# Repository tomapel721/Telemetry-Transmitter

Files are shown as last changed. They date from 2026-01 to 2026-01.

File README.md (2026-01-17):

## :book: Long story short
The transmitter part of telemetry system which was implemented inside a Formula Student EV.

## :computer: How it works - technologies
PCB Design: **KiCad**

Project source code: **C (C18) with usage of HAL libraries**
Board used: **STM32L432KC**

## :file_folder: Repository structure
In main directory, you can find 2 folders:
- directory **PCBDesign** contains project of printed circuit used as HW part of the telemetry transmitter
- directory **SourceCode** contains the SW part of the project
obraz

## :scroll: How to use my code
Usage of the code can be hard to do, but in case you want to make your own racing car, here is the brief manual:
1. Print the PCB using the _GERBER_ files
2. Solder the board elements
3. Connect soldered electronics to PC
4. Flash the STM32 using ST-LINK debugger (pins where to connect are marked on the PCB schema)
5. Enjoy;)

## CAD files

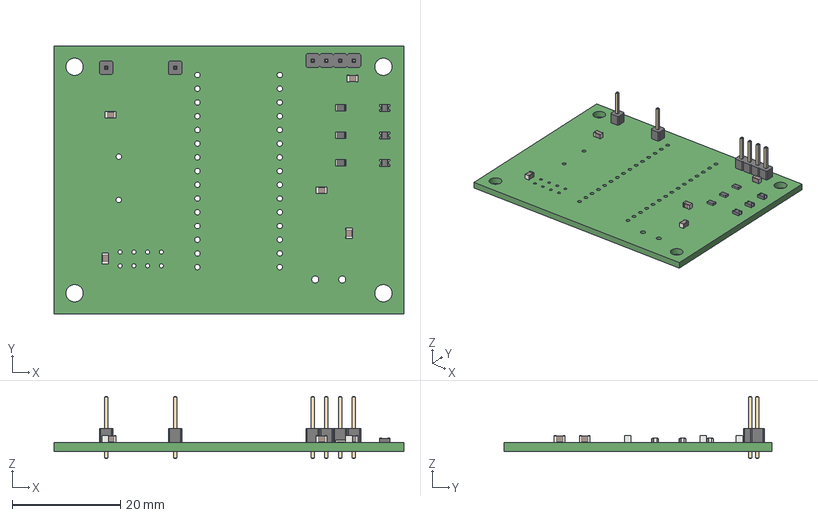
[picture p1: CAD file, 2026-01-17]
Transmitter/PCBDesign/Telemetry.step
64.8 x 49.5 x 11.5 mm

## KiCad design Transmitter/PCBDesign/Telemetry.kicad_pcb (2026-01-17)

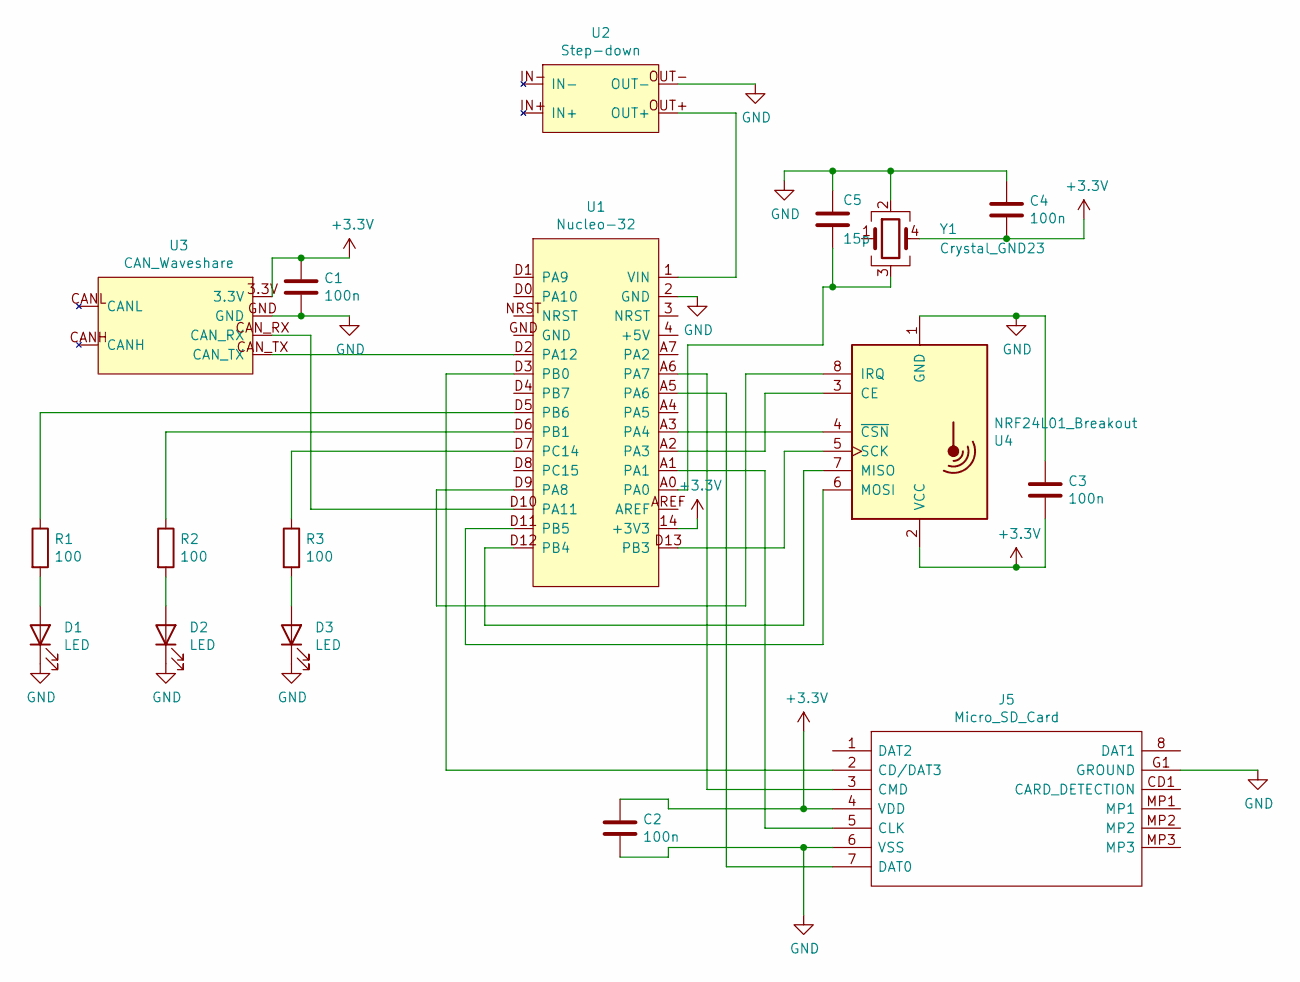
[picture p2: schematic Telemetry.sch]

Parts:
C1, C2, C3, C4: 100n; C_0805_2012Metric
C5: 15p; C_0805_2012Metric
D1, D2, D3: LED; D_0805_2012Metric_Pad1.15x1.40mm_HandSolder
J5: Micro_SD_Card; 112JTDARR01; Manufacturer_Part_Number 112J-TDAR-R01
R1, R2, R3: 100; R_0805_2012Metric_Pad1.20x1.40mm_HandSolder
U1: Nucleo-32; Arduino_Nano
U2: Step-down; TerminalBlock_RND_205-00012_1x02_P5.00mm_Horizontal
U3: CAN_Waveshare; PinHeader_1x04_P2.54mm_Vertical
U4: NRF24L01_Breakout; nRF24L01_Breakout
Y1: Crystal_GND23; Crystal_SMD_7050-4Pin_7.0x5.0mm

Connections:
+3V3: C1.1, C2.1, C3.2, C4.2, J5.4 (VDD), U1.14 (+3V3), U3.3.3V, U4.2 (VCC), Y1.4
GND: C1.2, C2.2, C3.1, C4.1, C5.1, D1.1 (K), D2.1 (K), D3.1 (K), J5.6 (VSS), J5.G1 (GROUND), U1.2 (GND), U2.OUT-, U3.GND, U4.1 (GND), Y1.2
unnamed: C5.2, U1.A0, Y1.3
unnamed: D1.2 (A), R1.2
unnamed: D2.2 (A), R2.2
unnamed: D3.2 (A), R3.2
unnamed: J5.2 (CD/DAT3), U1.D3 (PB0)
unnamed: J5.3 (CMD), U1.A6 (PA7)
unnamed: J5.5 (CLK), U1.A1
unnamed: J5.7 (DAT0), U1.A5 (PA6)
unnamed: R1.1, U1.D5 (PB6)
unnamed: R2.1, U1.D6 (PB1)
unnamed: R3.1, U1.D7 (PC14)
unnamed: U1.1 (VIN), U2.OUT+
unnamed: U1.A2 (PA3), U4.3 (CE)
unnamed: U1.A3 (PA4), U4.4 (~CSN)
unnamed: U1.D2 (PA12), U3.CAN_TX
unnamed: U1.D9 (PA8), U4.8 (IRQ)
unnamed: U1.D10 (PA11), U3.CAN_RX
unnamed: U1.D11 (PB5), U4.6 (MOSI)
unnamed: U1.D12 (PB4), U4.7 (MISO)
unnamed: U1.D13 (PB3), U4.5 (SCK)

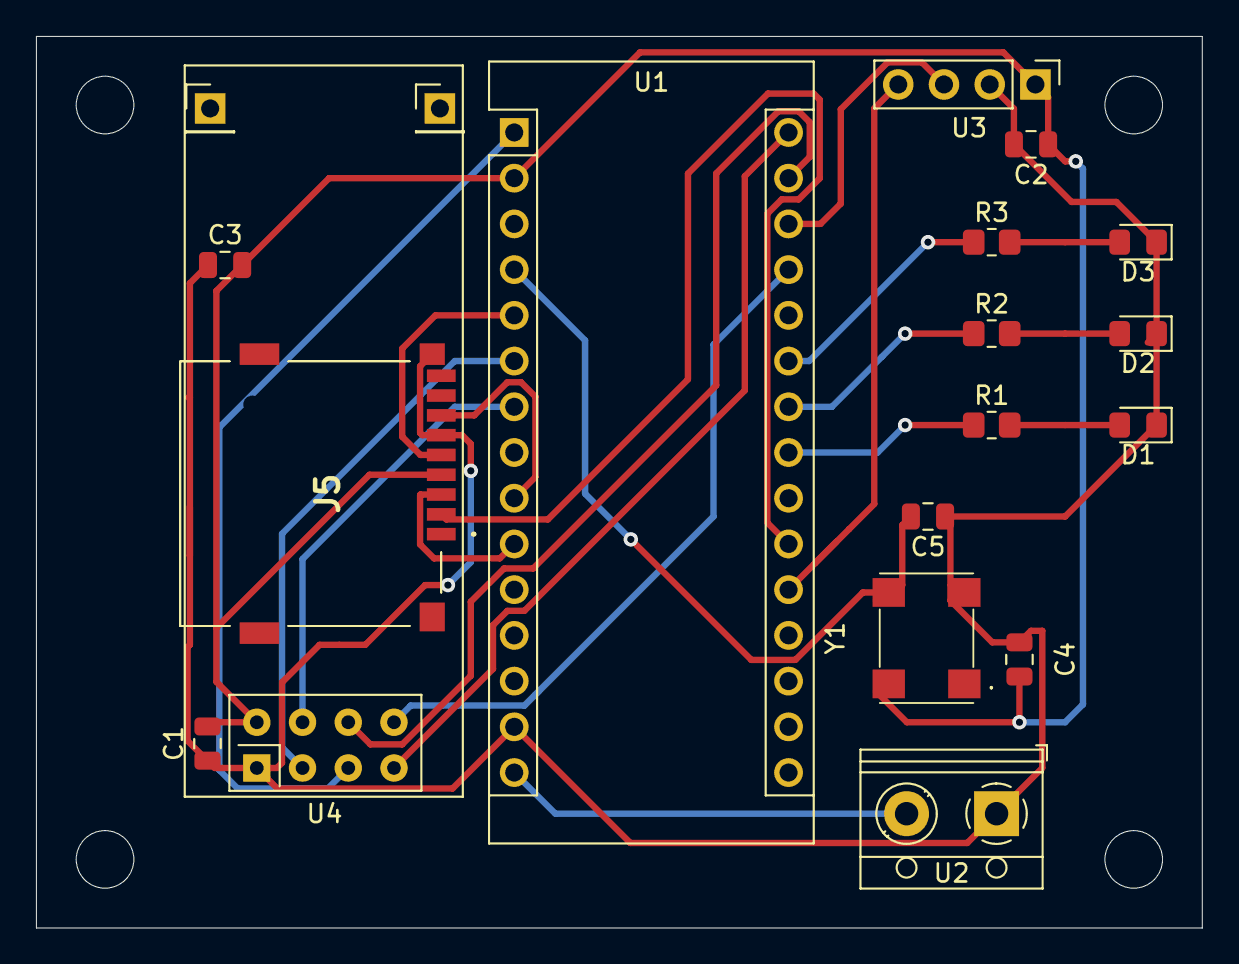
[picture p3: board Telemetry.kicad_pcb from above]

Board: 2 copper layers, 64.8 x 49.5 mm, 23 parts (0 on the bottom side), 22 nets.

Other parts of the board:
 : .; PinHeader_1x01_P2.54mm_Vertical
 #2: .; PinHeader_1x01_P2.54mm_Vertical
 #3,  #4,  #5,  #6: M3; MountingHole_3.2mm_M3_DIN965

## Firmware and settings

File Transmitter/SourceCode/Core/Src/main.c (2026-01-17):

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
/* Includes ------------------------------------------------------------------*/
#include "main.h"
#include "can.h"
#include "fatfs.h"
#include "rtc.h"
#include "spi.h"
#include "usart.h"
#include "gpio.h"

/* USER CODE BEGIN Includes */

#include "stdio.h"
#include "fatfs_sd.h"
#include "string.h"
#include <stdbool.h>
#include <NRF24/nRF24.h>
#include <NRF24/nRF24_Defs.h>
#include <Buffer/frame.h>
#include <SD/SD_helpers.h>
/* USER CODE END Includes */

/* USER CODE BEGIN PD */
#define CAN_DATA_LENGTH 8
#define FILENAME_BUFFER_LENGTH 35
#define SD_CARD_MOUNT_IMMEDIATELY 1
#define TIME_SECONDS_IN_HOUR 3600
#define TIME_MINUTES_IN_HOUR 60
#define TIME_MILISECONDS_IN_SECOND 1000000
#define SECOND_MILLENIUM 2000
/* USER CODE END PD */


void SystemClock_Config(void);
/* USER CODE BEGIN PFP */
static void readDataToBuffer(void);
/* USER CODE END PFP */

/* USER CODE BEGIN 0 */

/* SD Card-related variables */
FATFS fs = {0};
FIL fil = {0};
FRESULT fresult = {0};
char filename[FILENAME_BUFFER_LENGTH] = {0};
UINT bw = 0;
uint8_t counterSD = 0;

/* CAN-related variables */
CAN_RxHeaderTypeDef rxHeader = {0};
uint8_t rxData[CAN_DATA_LENGTH] = {0};

/* CAN buffer */
Frame bufferingFrame = {0};

/* RTC-related variables */
RTC_TimeTypeDef currentTime = {0};
RTC_DateTypeDef currentDate = {0};
uint32_t miliseconds = 0;
uint32_t seconds = 0;

/* IRQ-related variables */
bool interruptFlag = false;

/* Radio module-related variables */
const uint8_t* rxAddress = (uint8_t*)"Nad";
const uint8_t* txAddress = (uint8_t*)"Odb";

/* USER CODE END 0 */

/**
  * @brief  The application entry point.
  * @retval int
  */
int main(void)
{
  /* MCU Configuration--------------------------------------------------------*/

  /* Reset of all peripherals, Initializes the Flash interface and the Systick. */
  HAL_Init();

  /* Configure the system clock */
  SystemClock_Config();

  /* Initialize all configured peripherals */
  MX_GPIO_Init();
  MX_SPI1_Init();
  MX_CAN1_Init();
  MX_RTC_Init();
  MX_USART2_UART_Init();
  MX_SPI3_Init();
  MX_FATFS_Init();
  /* USER CODE BEGIN 2 */

  /* CAN init */
  HAL_CAN_Start(&hcan1);
  HAL_CAN_ActivateNotification(&hcan1, CAN_IT_RX_FIFO0_MSG_PENDING);

  /* Radio module init */
  nRF24_Init(&hspi3);
  nRF24_SetRXAddress(0, rxAddress);
  nRF24_SetTXAddress(txAddress);
  nRF24_TX_Mode();

  /* SD card mount */
   fresult = f_mount(&fs, "/", SD_CARD_MOUNT_IMMEDIATELY);

  /* Handle naming of file on SD card */
   HAL_RTC_GetTime(&hrtc, &currentTime, RTC_FORMAT_BIN);
   HAL_RTC_GetDate(&hrtc, &currentDate, RTC_FORMAT_BIN);
   miliseconds = ((currentTime.SecondFraction - currentTime.SubSeconds)/((float)currentTime.SecondFraction+1) * TIME_MILISECONDS_IN_SECOND);
   sprintf(filename, "LOG_%02d%02d%d_%02d%02d_%02d_%lu.txt", currentDate.Date,
		   currentDate.Month, currentDate.Year + SECOND_MILLENIUM, currentTime.Hours,
		   currentTime.Minutes, currentTime.Seconds, miliseconds);
  /* USER CODE END 2 */

  /* Infinite loop */
  /* USER CODE BEGIN WHILE */
  while (1)
  {

	  /* Radio module interrupt checker */
	  nRF24_Event();

	  /* Handling of received packet */
	  if(interruptFlag)
	  {
		 readDataToBuffer();
	  }

    /* USER CODE END WHILE */

    /* USER CODE BEGIN 3 */
  }
  /* USER CODE END 3 */
}

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
/* USER CODE BEGIN 4 */

/* Radio module interrupt callback */
void HAL_GPIO_EXTI_Callback(uint16_t GPIO_Pin)
 {
	if(GPIO_Pin == NRF24_IRQ_Pin)
	{
		nRF24_IRQ_Handler();
	}
}

/* CAN message received callback */
void HAL_CAN_RxFifo0MsgPendingCallback(CAN_HandleTypeDef* hcan)
{
	HAL_CAN_GetRxMessage(hcan, CAN_RX_FIFO0, &rxHeader, rxData);
	interruptFlag = true;
}

/* Function reads data, pack it into buffer and save data to SD card */
static void readDataToBuffer(void)
{
	HAL_RTC_GetTime(&hrtc, &currentTime, RTC_FORMAT_BIN);
	HAL_RTC_GetDate(&hrtc, &currentDate, RTC_FORMAT_BIN);
	bufferingFrame.year = currentDate.Year;
	bufferingFrame.month = currentDate.Month;
	bufferingFrame.day = currentDate.Date;
	bufferingFrame.hours = currentTime.Hours;
	bufferingFrame.minutes = currentTime.Minutes;
	bufferingFrame.seconds = currentTime.Seconds;
	miliseconds = ((currentTime.SecondFraction - currentTime.SubSeconds)/((float)currentTime.SecondFraction+1) * TIME_MILISECONDS_IN_SECOND);
	seconds = TIME_SECONDS_IN_HOUR * currentTime.Hours + TIME_MINUTES_IN_HOUR * currentTime.Minutes + currentTime.Seconds;
	memcpy(bufferingFrame.frameData, rxData, CAN_DATA_LENGTH);

	bufferingFrame.frameDLC = rxHeader.DLC;
	bufferingFrame.frameIDE = rxHeader.IDE;
	bufferingFrame.frameRTR = rxHeader.RTR;
	bufferingFrame.frameStdID = rxHeader.StdId;

	writeFrameToSDCard(&bufferingFrame);
	nRF24_SendData((uint8_t*)&bufferingFrame, sizeof(Frame));

	interruptFlag = false;
}

/* USER CODE END 4 */
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


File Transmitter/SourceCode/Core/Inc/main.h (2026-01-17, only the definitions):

#define NRF24_CE_Pin GPIO_PIN_3
#define NRF24_CE_GPIO_Port GPIOA
#define NRF24_CSN_Pin GPIO_PIN_4
#define NRF24_CSN_GPIO_Port GPIOA
#define NRF24_IRQ_Pin GPIO_PIN_8
#define NRF24_IRQ_GPIO_Port GPIOA
#define NRF24_IRQ_EXTI_IRQn EXTI9_5_IRQn

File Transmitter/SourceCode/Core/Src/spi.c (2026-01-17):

/**
  ******************************************************************************
  * @file    spi.c
  * @brief   This file provides code for the configuration
  *          of the SPI instances.
  ******************************************************************************
  * @attention
  *
  * <h2><center>&copy; Copyright (c) 2021 STMicroelectronics.
  * All rights reserved.</center></h2>
  *
  * This software component is licensed by ST under Ultimate Liberty license
  * SLA0044, the "License"; You may not use this file except in compliance with
  * the License. You may obtain a copy of the License at:
  *                             www.st.com/SLA0044
  *
  ******************************************************************************
  */

/* Includes ------------------------------------------------------------------*/
#include "spi.h"

SPI_HandleTypeDef hspi1;
SPI_HandleTypeDef hspi3;

/* SPI1 init function */
void MX_SPI1_Init(void)
{

  hspi1.Instance = SPI1;
  hspi1.Init.Mode = SPI_MODE_MASTER;
  hspi1.Init.Direction = SPI_DIRECTION_2LINES;
  hspi1.Init.DataSize = SPI_DATASIZE_8BIT;
  hspi1.Init.CLKPolarity = SPI_POLARITY_LOW;
  hspi1.Init.CLKPhase = SPI_PHASE_1EDGE;
  hspi1.Init.NSS = SPI_NSS_SOFT;
  hspi1.Init.BaudRatePrescaler = SPI_BAUDRATEPRESCALER_32;
  hspi1.Init.FirstBit = SPI_FIRSTBIT_MSB;
  hspi1.Init.TIMode = SPI_TIMODE_DISABLE;
  hspi1.Init.CRCCalculation = SPI_CRCCALCULATION_DISABLE;
  hspi1.Init.CRCPolynomial = 7;
  hspi1.Init.CRCLength = SPI_CRC_LENGTH_DATASIZE;
  hspi1.Init.NSSPMode = SPI_NSS_PULSE_ENABLE;
  if (HAL_SPI_Init(&hspi1) != HAL_OK)
  {
    Error_Handler();
  }
}
/* SPI3 init function */
void MX_SPI3_Init(void)
{

  hspi3.Instance = SPI3;
  hspi3.Init.Mode = SPI_MODE_MASTER;
  hspi3.Init.Direction = SPI_DIRECTION_2LINES;
  hspi3.Init.DataSize = SPI_DATASIZE_8BIT;
  hspi3.Init.CLKPolarity = SPI_POLARITY_LOW;
  hspi3.Init.CLKPhase = SPI_PHASE_1EDGE;
  hspi3.Init.NSS = SPI_NSS_SOFT;
  hspi3.Init.BaudRatePrescaler = SPI_BAUDRATEPRESCALER_32;
  hspi3.Init.FirstBit = SPI_FIRSTBIT_MSB;
  hspi3.Init.TIMode = SPI_TIMODE_DISABLE;
  hspi3.Init.CRCCalculation = SPI_CRCCALCULATION_DISABLE;
  hspi3.Init.CRCPolynomial = 7;
  hspi3.Init.CRCLength = SPI_CRC_LENGTH_DATASIZE;
  hspi3.Init.NSSPMode = SPI_NSS_PULSE_ENABLE;
  if (HAL_SPI_Init(&hspi3) != HAL_OK)
  {
    Error_Handler();
  }
}

void HAL_SPI_MspInit(SPI_HandleTypeDef* spiHandle)
{

  GPIO_InitTypeDef GPIO_InitStruct = {0};
  if(spiHandle->Instance==SPI1)
  {
    /* SPI1 clock enable */
    __HAL_RCC_SPI1_CLK_ENABLE();

    __HAL_RCC_GPIOA_CLK_ENABLE();
    /**SPI1 GPIO Configuration
    PA1     ------> SPI1_SCK
    PA6     ------> SPI1_MISO
    PA7     ------> SPI1_MOSI
    */
    GPIO_InitStruct.Pin = GPIO_PIN_1|GPIO_PIN_6|GPIO_PIN_7;
    GPIO_InitStruct.Mode = GPIO_MODE_AF_PP;
    GPIO_InitStruct.Pull = GPIO_NOPULL;
    GPIO_InitStruct.Speed = GPIO_SPEED_FREQ_VERY_HIGH;
    GPIO_InitStruct.Alternate = GPIO_AF5_SPI1;
    HAL_GPIO_Init(GPIOA, &GPIO_InitStruct);

  }
  else if(spiHandle->Instance==SPI3)
  {
    /* SPI3 clock enable */
    __HAL_RCC_SPI3_CLK_ENABLE();

    __HAL_RCC_GPIOB_CLK_ENABLE();
    /**SPI3 GPIO Configuration
    PB3 (JTDO-TRACESWO)     ------> SPI3_SCK
    PB4 (NJTRST)     ------> SPI3_MISO
    PB5     ------> SPI3_MOSI
    */
    GPIO_InitStruct.Pin = GPIO_PIN_3|GPIO_PIN_4|GPIO_PIN_5;
    GPIO_InitStruct.Mode = GPIO_MODE_AF_PP;
    GPIO_InitStruct.Pull = GPIO_NOPULL;
    GPIO_InitStruct.Speed = GPIO_SPEED_FREQ_VERY_HIGH;
    GPIO_InitStruct.Alternate = GPIO_AF6_SPI3;
    HAL_GPIO_Init(GPIOB, &GPIO_InitStruct);

  }
}

void HAL_SPI_MspDeInit(SPI_HandleTypeDef* spiHandle)
{

  if(spiHandle->Instance==SPI1)
  {
    /* Peripheral clock disable */
    __HAL_RCC_SPI1_CLK_DISABLE();

    /**SPI1 GPIO Configuration
    PA1     ------> SPI1_SCK
    PA6     ------> SPI1_MISO
    PA7     ------> SPI1_MOSI
    */
    HAL_GPIO_DeInit(GPIOA, GPIO_PIN_1|GPIO_PIN_6|GPIO_PIN_7);

  }
  else if(spiHandle->Instance==SPI3)
  {
    /* Peripheral clock disable */
    __HAL_RCC_SPI3_CLK_DISABLE();

    /**SPI3 GPIO Configuration
    PB3 (JTDO-TRACESWO)     ------> SPI3_SCK
    PB4 (NJTRST)     ------> SPI3_MISO
    PB5     ------> SPI3_MOSI
    */
    HAL_GPIO_DeInit(GPIOB, GPIO_PIN_3|GPIO_PIN_4|GPIO_PIN_5);

  }
}

/************************ (C) COPYRIGHT STMicroelectronics *****END OF FILE****/

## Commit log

2026-01-17 Upload latest files
    [Telemetry-B_Cu.gbr, Telemetry-B_Mask.gbr, Telemetry-B_Paste.gbr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]
2026-01-17 Code refactoring
    - Fixed application code warning on -Wextra and -pedantic level
    - Improved code structure
    * Introduced new dir for SD related files
    - Fixed magic numbers
    - Slight optimization in arguments passed to functions
    [main.c, nRF24.c]

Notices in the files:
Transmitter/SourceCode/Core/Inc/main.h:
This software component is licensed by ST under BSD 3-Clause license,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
